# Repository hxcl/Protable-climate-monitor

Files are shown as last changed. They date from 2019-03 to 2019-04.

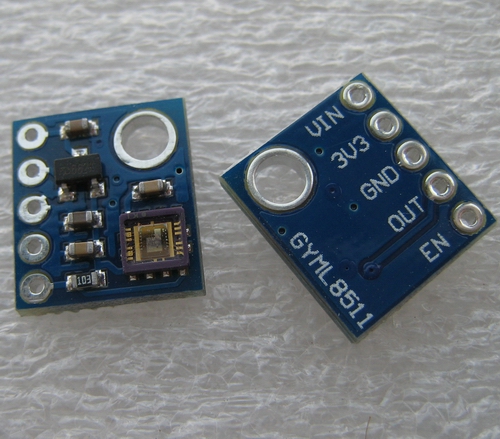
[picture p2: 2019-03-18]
sensor/ultraviolet sensor/GYML8511资料/ML8511-1.JPG

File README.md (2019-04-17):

# 便携式气候监测仪
最终代码和模型在Final文件夹内

---

确定的方案为：

* 智能窗户

  > 可根据室外环境智能打开/关闭百叶窗，用于宿舍
  >
  > 上位机可拆卸并随身携带，用于旅途

  分为两部分：

  * 上位机：便携模块

    需要的器件有：

    * 芯片为51单片机或Arduino
    * 温度传感器，湿度传感器，光传感器，（未确定：红外传感器，PM2.5传感器）
    * OLED屏幕
    * 微动按键/触摸按键

  * 下位机：驱动模块

    需要的器件有：

    * 百叶窗(59*90cm)
    * 步进电机
    * 驱动芯片（51单片机或Arduino）

用户操作：

* 安装：

  将百叶窗装好后，将电机转子安装到转轴处，将电机外壳与驱动模块固定住，驱动模块接上电源（mirco USB与手机充电器），将便携模块插到驱动模块上。

* 设定驱动模块：

  按驱动模块的`开窗`或`关窗`键将百叶窗调到中间状态，再按`复位`键，指示灯闪烁，则驱动模块完成预设。

* 设定便携模块：

  打开开关，屏幕会显示当前的温度、湿度、光照强度和紫外线强度，则此时工作正常；

  便携模块已根据广东的天气预设了智能关窗的阈值，也可以手动设置阈值。按`设置`按钮，此时屏幕上闪烁的为温度阈值，按`上`和`下`键调整；再`设置`键可切换到其他参数。只要有任意一项达到阈值，窗户就会关闭。未达到阈值时，窗户会线性调整开合角度。

* 便携模块的移动使用：

  将便携模块取下，可随身携带，适合旅游时了解当地的天气情况。只需要拿出来，将有传感器一面向上，按`显示`键，即可显示此时的天气，进而决定是否需要涂防晒霜/打遮阳伞。可以将它挂在包外实时监测，若超过阈值，指示灯显示为红色。

---

讨论后放弃的方案有这几种：

* 智能门锁

  > 用人脸识别开宿舍门

* 智能坐垫

  > 体重记录，久坐提醒
  >
  > 图书馆座位管理
* 智能书箱

  >智能准备第二天的书
* 智能运输车

  >自动跟随运输车

* 智能ppt

  >用语音控制ppt翻页

* 智能收作业

  > 用RFID管理身份，自动分类

* 智能

另外记录一个创意: 

* 共享校园网

  > 收集大二、大三、大四同学限制的校园网账号，储存在服务器中
  >
  > 大一同学付费后，可通过软件自动联网

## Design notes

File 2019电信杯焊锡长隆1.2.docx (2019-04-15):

FinO便携气候监测仪

——智能百叶窗

队伍名 焊锡长隆

队长 周镇峰

队员 刘宇帆

队员 杨联标

# 1、 功能说明和选题背景

FinO便携气候监测仪（以下简称FinO）可以监测紫外线强度，光照强度、温度和湿度，并通过屏幕显示出来。其体积小，待机长，可随身携带，随时随地得到当前位置的气候信息，弥补天气预报泛而不精的缺点，从而帮助您决定是否要增添衣服、涂抹防晒霜。

另外，FinO还可通过FinO特殊的USB口将数据输出。你只需将FinO插入FinO生态设备，即可享受智能家居。比如在这个项目中，我们打造了一个智能百叶窗，它能根据光照调智能整开合角度，让您的室内舒适明亮。未来，将有更多设备加入FinO生态。

# 二、整机电路

## 2.1 原理方框图

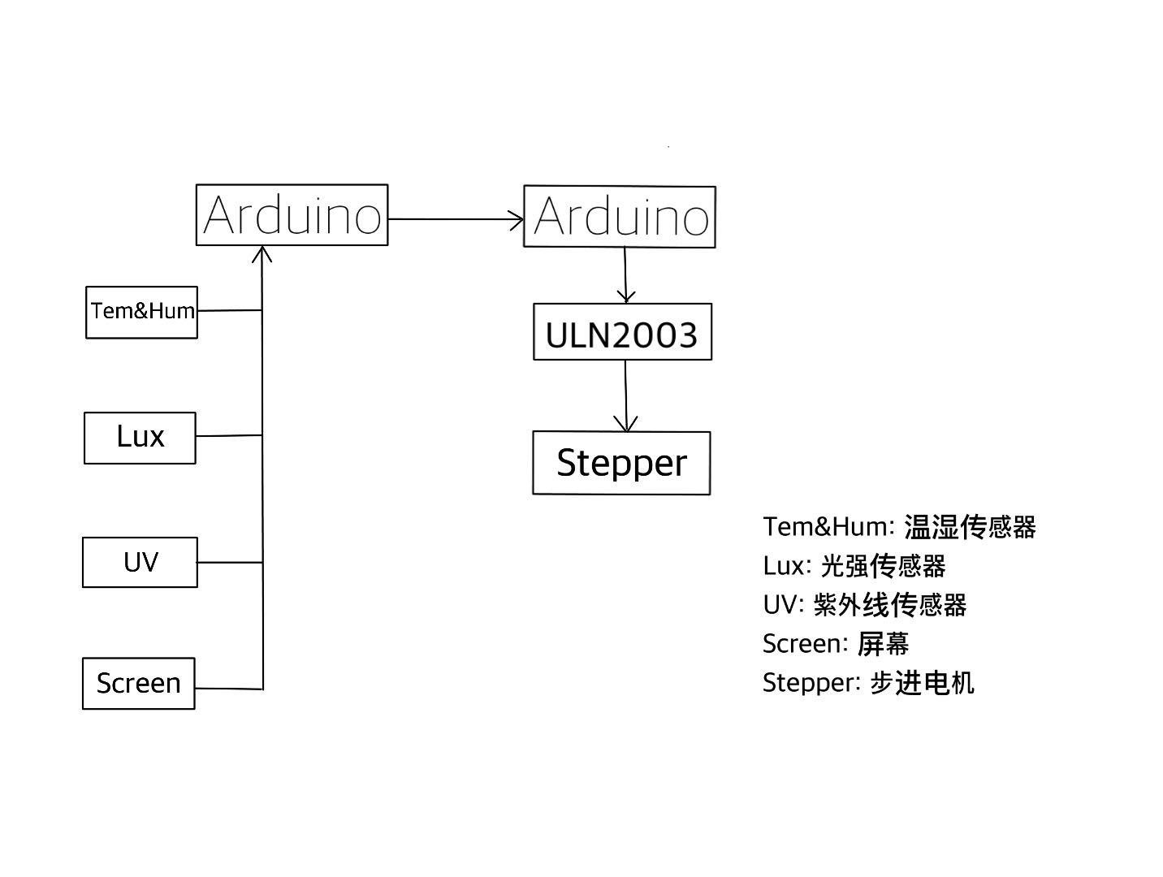
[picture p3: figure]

（图2.1）

## 2.2 整机电路图

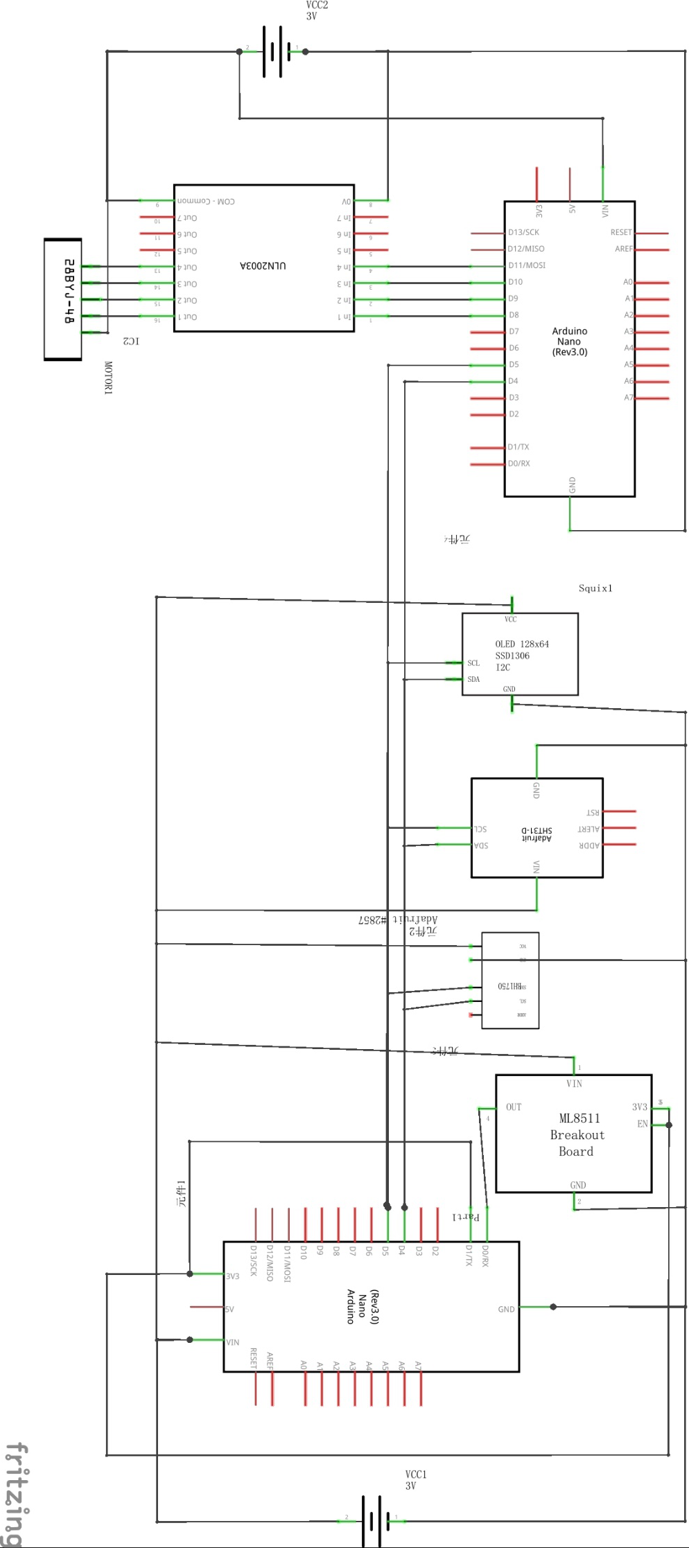
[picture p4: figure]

## （图2.2-1）

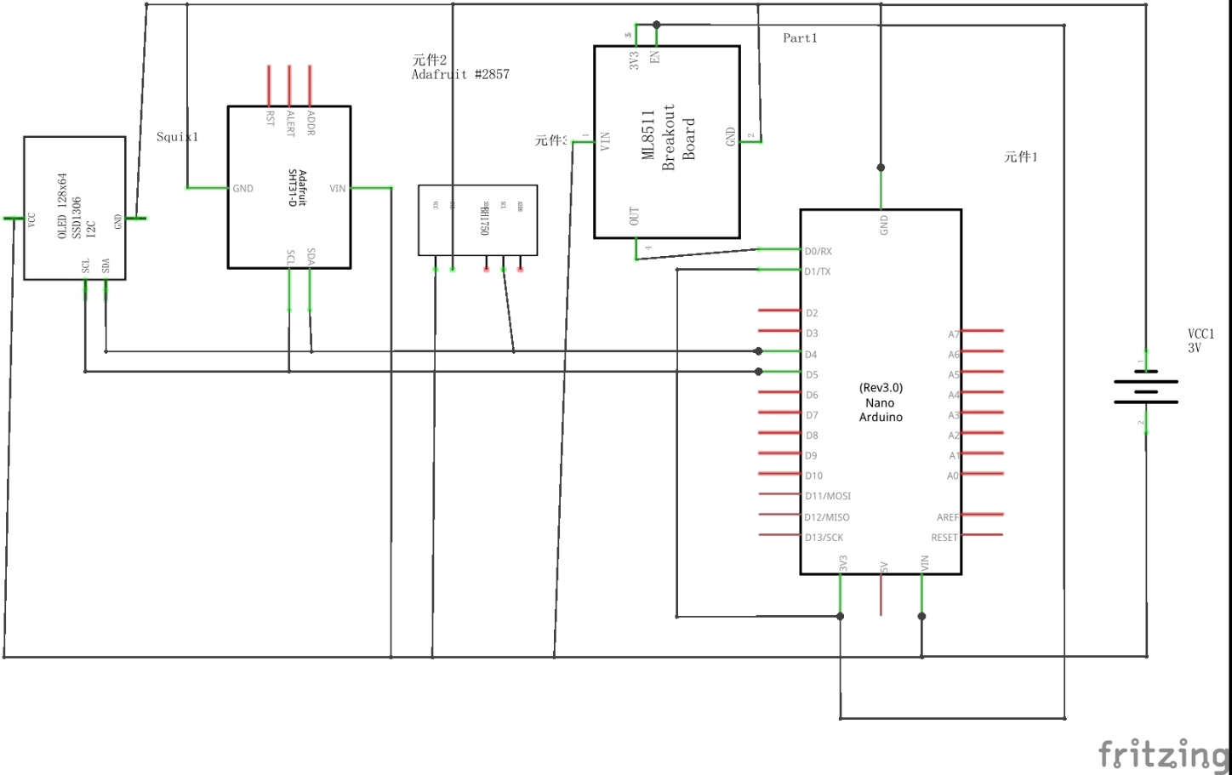
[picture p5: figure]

(图2.2-2)

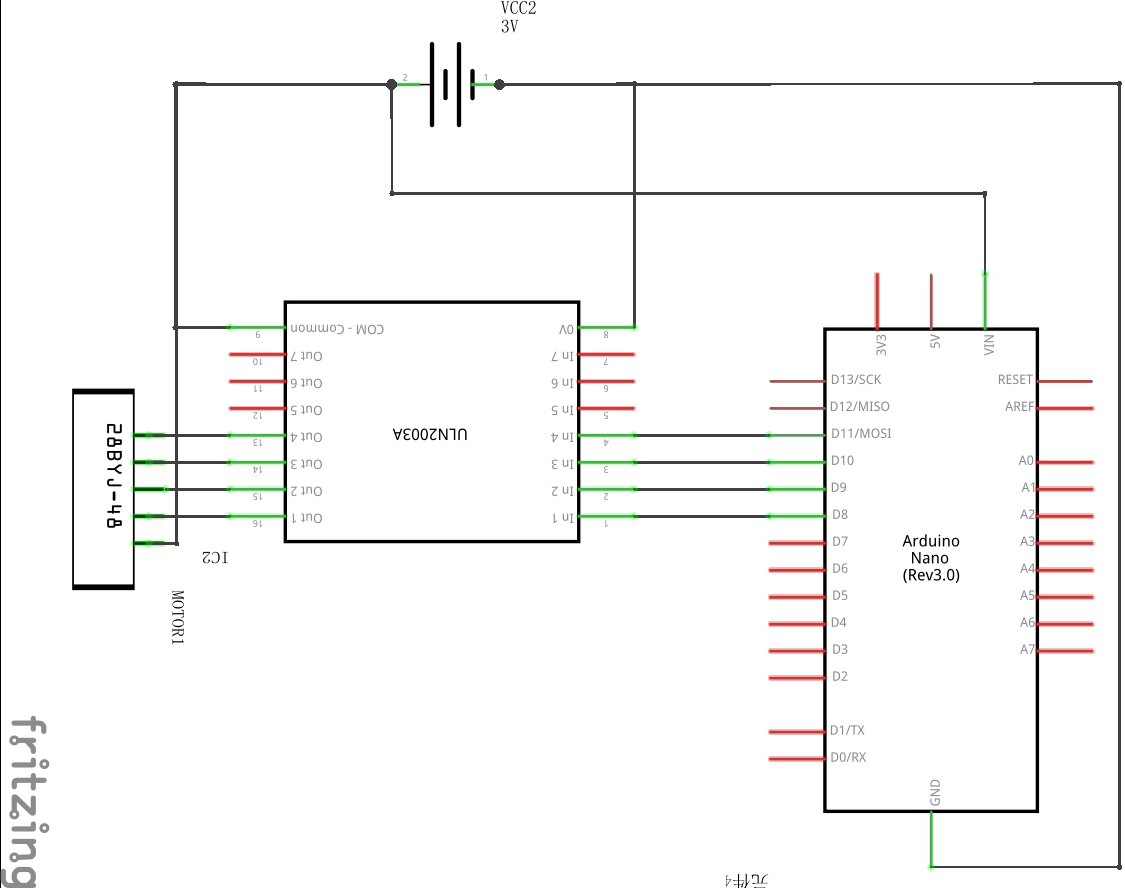
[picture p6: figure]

（图2.2-3）

# 三、单元电路设计

## 3.1 温湿度传感器模块——SHT3x-DIS

### 3.1.1 模块单元电路图

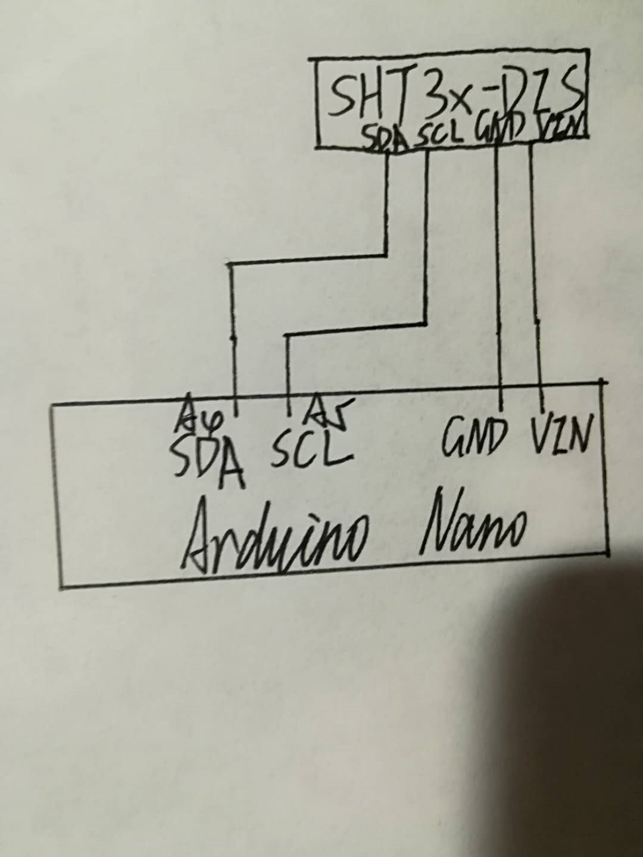
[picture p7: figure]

（图3.1.1）

### 3.1.2 核心元件简介

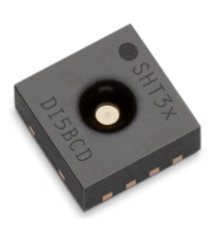
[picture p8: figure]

（图3.1.2）

SHT3x-DIS是校准刻度线性化的温湿度传感器。它的工作电压从2.4V到5.5V，使用I2C通信，拥有两个供用户选择的地址，精度范围为正负2%RH和正负0.3%摄氏度

### 3.1.3 模块功能及工作原理

温度测量的原理是：采用热电偶的方法，热电偶由两种不同材料的金属丝组成，两种丝材的一端焊接在一起，形成工作端，置于被测温度处；另一端称为自由端，与测量仪表相连，形成一个闭合回路。当工作端与自由端的温度不同时，回路中就会出现热电动势，经过电路的转换将这个电压的变化送到单片机，转化成机器能够识别的信号。

湿度测量的原理是：使用沉积在两个导电电极上的聚胺盐或醋酸纤维聚合物薄膜。当薄膜吸水或失水后，会改变两个电极间的介电常数，进而引起电容器容量的变化，利用外部测量电路可将电容器的容量变化进行捕捉、转化处理，最终在输出端显示成易识别的信号。

## 3.2 紫外线传感器模块

### 3.2.1 模块单元电路图（图3.2.1）

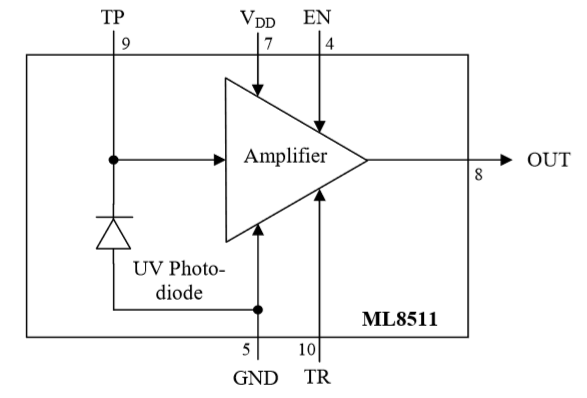
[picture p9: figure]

### 3.2.2 核心元件简介

ML8511紫外线传感器可读取室内或户外的紫外线强度，并转化为电压输出。

### 3.2.3 模块功能及工作原理

ML8511内部的光电二极管对UV-A和UV-B两种紫外线敏感（UV-C已被臭氧层吸收，无需测量），光电二极管产生的光电流通过运算放大器转换为电压。在-25℃到75℃的范围内，0~15级紫外线强度线性地输出为1~3伏电压。

## 3.3 光照强度传感器模块

### 3.3.1 模块单元电路图

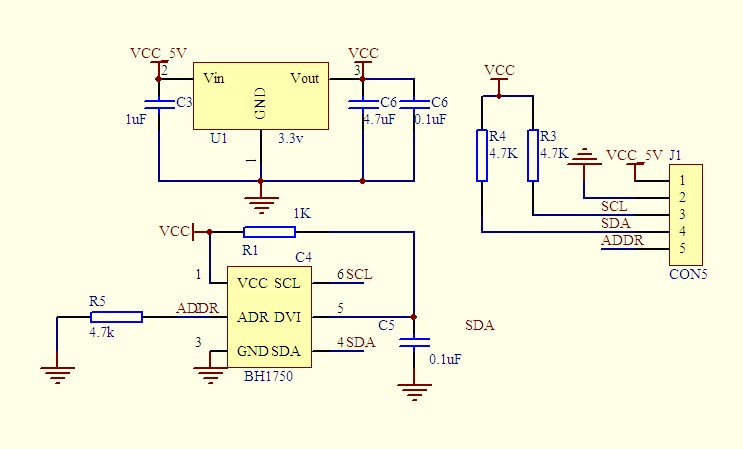
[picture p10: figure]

（图3.3.1）

### 3.3.2 核心元件简介

BH1750FVI是一种使用I2C协议的数字环境光传感集成电路。该集成电路最适合于获取手机LCD和键盘背光电源调节所需的环境光数据。拥有极高的感光范围（1-65536流明）。

### 3.2.3 模块功能及工作原理

### BH1750通过光敏二极管测量光强，光强信号经过集成运算放大器处理后输出

## 3.4 OLED显示屏模块

### 3.4.1 模块单元电路图

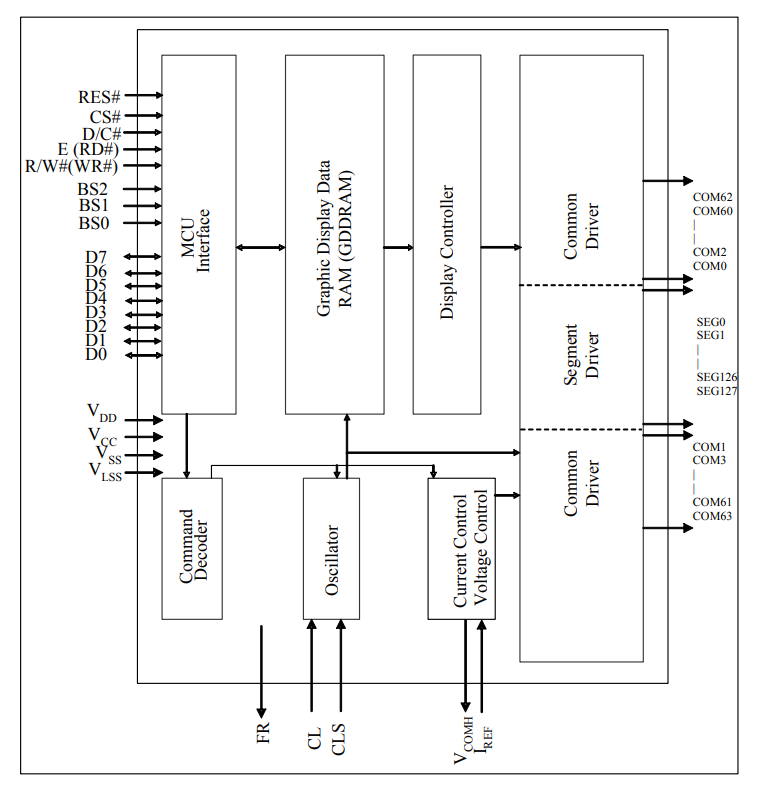
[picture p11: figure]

（图3.4.1）

### 3.4.2 核心元件简介

OLED显示屏模块分辨率为128x64，驱动芯片为SSD1306，采用I2C通信。

### 3.4.3 模块功能及工作原理

OLED（Organic Light-Emitting Diode）称为有机发光二极管，其原理为：在外界电压的驱动下，由电极注入的电子和空穴在发光层中复合形成处于束缚能级的电子空穴对即激子，激子辐射退激发发出光子，产生可见光。

利用U8g2lib库向SSD1306的缓冲区写入像素，再由SSD1306输出到OLED屏幕上

## 3.5 步进电机模块

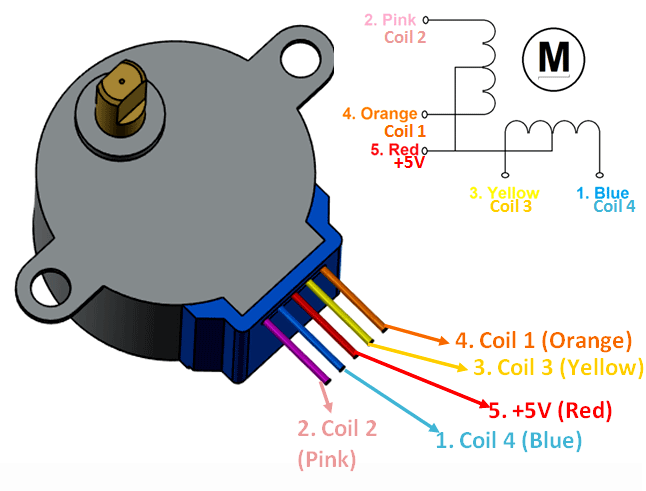
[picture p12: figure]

### 3.5.1 模块单元电路图

（图3.5.1-1）

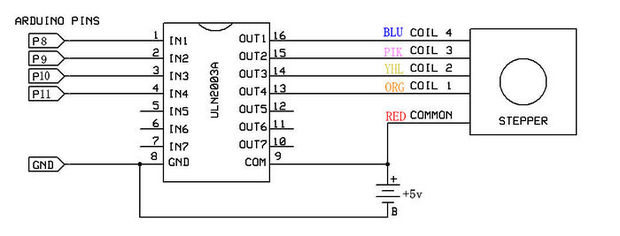
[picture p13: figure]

(图3.5.1-2)

### 3.5.2 核心元件简介

28BYJ48为常见的5V五线四相步进电机，利用ULN2003作为驱动芯片。

### 3.5.3 模块功能及工作原理

步进电机用于开关百叶窗，其原理为：按一定时序给定子通电，使其产生一个旋转的磁场，从而带动永磁式转子转动。

由于Arduino不能直接驱动功率较大的步进电机，采用ULN2003驱动。ULN2003的原理为：输入通过达林顿三极管控制反相输出。

# 四、程序代码

## 主机程序：

#include<Arduino.h>

#include <U8g2lib.h>

#include <Wire.h>

#include "SHTSensor.h"

SHTSensor sht;//温湿度传感器的对象

int BH1750address=0x23;//光强传感器地址

byte buff[2];

int UVOUT = A0; //Output from the sensor

int REF_3V3 = A1; //3.3V power on the Arduino board

unsigned int time=0;

float Lux,Tem,Hum,Uv,UVMAX=0;

U8G2_SSD1306_128X64_NONAME_F_HW_I2C u8g2(U8G2_R0, /* reset=*/ U8X8_PIN_NONE);

void setup() {

Serial.begin(9600);

u8g2.setI2CAddress(0x78);//屏幕地址

u8g2.begin();

Wire.begin();

}

void loop() {

firstDisplay();

u8g2.setFont(u8g2_font_victoriabold8_8r);

while(1){

u8g2.clearBuffer();

u8g2.drawFrame(4,4,120,56);

u8g2.drawHLine(4,32,120);

u8g2.drawVLine(64,4,56); //以上是屏幕初始化

float X,Y,Z;

int L=0;

tem_hum(X,Y); //读取温湿度X是温度，Y是湿度

uv(Z); //读取紫外线指数

L=light(); //读取光强

Trans(); //传输光强

if(UVMAX<Z) //以下是屏幕显示

{

UVMAX=Z;

}

u8g2.setCursor(6,13);

u8g2.print("Temp:");

u8g2.setCursor(6,26);

u8g2.print(X);

u8g2.setCursor(66,13);

u8g2.print("Hum:");

u8g2.setCursor(66,26);

u8g2.print(Y);

u8g2.setCursor(6,41);

u8g2.print("Lux:");

u8g2.setCursor(6,54);

u8g2.print(L);

u8g2.setCursor(66,41);

u8g2.print("UV:");

u8g2.setCursor(66,54);

u8g2.print(UVMAX);

u8g2.sendBuffer();

delay(2000);

}

}

//HXCL logo

void firstDisplay(){

u8g2.clear();

u8g2.setFont(u8g2_font_maniac_tr);

u8g2.drawBox(4,4,120,56);

u8g2.setDrawColor(0);

u8g2.setFontMode(1);

u8g2.drawStr(25,40,"HXCL");

u8g2.sendBuffer();

u8g2.setDrawColor(1);

delay(1500);

}

void Trans() //传输函数

{

Wire.beginTransmission(0x99);//括号内补充从机地址

Wire.write(buff [0]);

Wire.write(buff [1]);

Wire.endTransmission();

}

void tem_hum(float &x,float &y) //获取温湿度函数

{

if (sht.init());

sht.setAccuracy(SHTSensor::SHT_ACCURACY_MEDIUM);

if (sht.readSample())

{

y=sht.getHumidity();x=sht.getTemperature();

}

}

void uv(float &uvIntensity) //获取紫外线函数

{

int uvLevel = averageAnalogRead(UVOUT);

int refLevel = averageAnalogRead(REF_3V3);

//Use the 3.3V power pin as a reference to get a very accurate output value from sensor

float outputVoltage = 3.3 / refLevel * uvLevel;

//uvIntensity = mapfloat(outputVoltage, 0.99, 2.9, 0.0, 15.0);

uvIntensity = (outputVoltage - 0.99) * 15.0 / 1.91;

}

//Takes an average of readings on a given pin

//Returns the average

int averageAnalogRead(int pinToRead)

{

byte numberOfReadings = 16;

unsigned int runningValue = 0;

for(int x = 0 ; x < numberOfReadings ; x++)

runningValue += analogRead(pinToRead);

runningValue /= numberOfReadings;

return(runningValue);

}

int light(){ //获取光强函数

int i;

double lux=0;

BH1750_Init(BH1750address);

if(2==BH1750_Read(BH1750address)){

lux=((buff[0]<<8)|buff[1])/1.2; //数据处理

}

return lux;

}

int BH1750_Read(int address){

int i=0;

Wire.beginTransmission(address);

Wire.requestFrom(address, 2);

while(Wire.available()){

buff[i] = Wire.read(); // receive one byte

i++;

}

Wire.endTransmission();

return i;

}

void BH1750_Init(int address){

Wire.beginTransmission(address);

Wire.write(0x10);//1lx reolution 120ms

Wire.endTransmission();

}

## 从机程序：

#include<Arduino.h>

#include <Wire.h>

#define IN1 8

#define IN2 9

#define IN3 10

#define IN4 11

int x[14];

int clockwise=0,states;

int a=200,b=500;//光强的上下界，初始值为起居室的适宜光强

unsigned int mode=1;//光照模式，0，1，2三档，初始值为第一档；

void rotate(int,int);

unsigned long triggertime=0;

union temp

{

float Float;

byte Byte[4];

}temp1;

void setup()

{

pinMode(IN1,OUTPUT);

pinMode(IN2,OUTPUT);

pinMode(IN3,OUTPUT);

pinMode(IN4,OUTPUT);

Serial.begin(9600);

rotate(102,0); //百叶窗启动调零

delay(1000);

rotate(102,0);

delay(1000);

rotate(102,0);

delay(1000);

rotate(102,0);

delay(1000);

rotate(102,1);

Wire.begin(0x99); //括号内补充本机地址，作为从机

Wire.onReceive(receiveEvent); //接收数据的函数

attachInterrupt(0,changeMode,FALLING); //添加按键中断

states=1;

}

void changeMode() //按键中断修改模式函数

{

if(millis()-triggertime>100) //消除抖动

{

triggertime=millis();

mode++;

mode=mode%3;

switch (mode)

{

case 0:a=0;b=200;break;

case 1:a=200;b=500;break;

case 2:a=500;b=800;break;

}

}

}

void receiveEvent()

{

int L;

while(Wire.available()>0)

{

for(int i=0;i<14;i++)

{

x[i]=Wire.read();

}

L=((x[0]<<8) | x[1])/1.2;

}

for(int i=2;i<6;i++)

{

temp1.Byte[i-2]=x[i];

}

Serial.println(temp1.Float);

for(int i=6;i<10;i++)

{

temp1.Byte[i-6]=x[i];

}

Serial.println(temp1.Float);

for(int i=10;i<14;i++)

{

temp1.Byte[i-10]=x[i];

}

Serial.println(temp1.Float);

Serial.println(L);

clockwise=judge(a,b,L);

if(clockwise==1&&states!=0) //states记录电机的当前位置

{

rotate(50,clockwise);

states--;

}

if(clockwise==0&&states!=10) //states记录电机的当前位置

{

rotate(50,clockwise);

states++;

}

}

int judge(int a,int b,float L) //判断当前光强是否是

{ //预定范围

if(L>=a&&L<=b) return -1;

else if(L<a) return 0;

else return 1;

}

void STEP(int i) //驱动步进电机的函数

{

switch (i)

{

case 0:

{

digitalWrite(IN1, 0);

digitalWrite(IN2, 1);

digitalWrite(IN3, 1);

digitalWrite(IN4, 1);

break;

}

case 1:

{

digitalWrite(IN1, 0);

digitalWrite(IN2, 0);

digitalWrite(IN3, 1);

digitalWrite(IN4, 1);

break;

}

case 2:

{

digitalWrite(IN1, 1);

digitalWrite(IN2, 0);

digitalWrite(IN3, 1);

digitalWrite(IN4, 1);

break;

}

case 3:

{

digitalWrite(IN1, 1);

digitalWrite(IN2, 0);

digitalWrite(IN3, 0);

digitalWrite(IN4, 1);

break;

}

case 4:

{

digitalWrite(IN1, 1);

digitalWrite(IN2, 1);

digitalWrite(IN3, 0);

digitalWrite(IN4, 1);

break;

}

case 5:

{

digitalWrite(IN1, 1);

digitalWrite(IN2, 1);

digitalWrite(IN3, 0);

digitalWrite(IN4, 0);

}

case 6:

{

digitalWrite(IN1, 1);

digitalWrite(IN2, 1);

digitalWrite(IN3, 1);

digitalWrite(IN4, 0);

break;

}

case 7:

{

digitalWrite(IN1, 0);

digitalWrite(IN2, 1);

digitalWrite(IN3, 1);

digitalWrite(IN4, 0);

break;

}

case 8:

{

digitalWrite(IN1, 0);

digitalWrite(IN2, 0);

digitalWrite(IN3, 0);

digitalWrite(IN4, 0);

break;

}

}

}

void rotate(int times, int clockwise=1)

{

//times为多少次8相，times=512对应一周。

//clockwise是标记顺逆时针，0为顺时针转动，1为逆时针转动

int j=times;

while(j--)

{

if(clockwise==0)

{

for(int i=0;i<8;++i)

{

STEP(i);

delay(2);

}

STEP(8);

delay(1);

}

if(clockwise==1)

{

for(int i=7;i>=0;--i)

{

STEP(i);

delay(2);

}

STEP(8);

delay(1);

}

}

}

void loop()

{

STEP(8);

delay(1000);

}

6 执着理想 勇于开拓

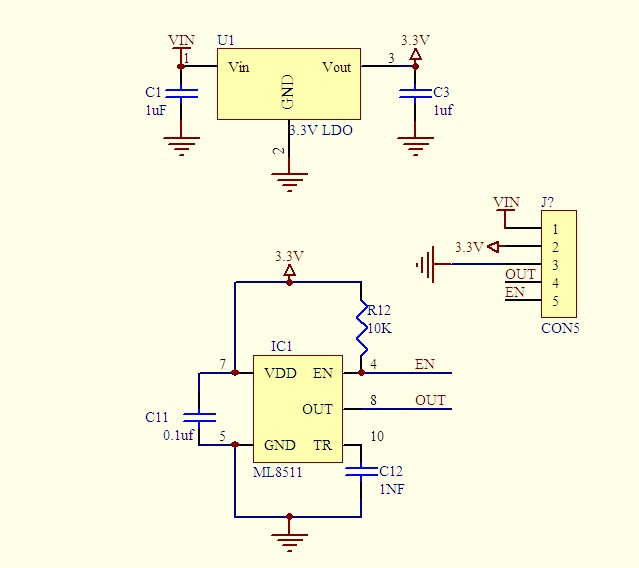
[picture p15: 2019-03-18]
sensor/ultraviolet sensor/GYML8511资料/GYML8511_SCH.jpg

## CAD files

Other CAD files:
sensor/muti-function sensor/GY-39/通信程序/C51/c51_usart/output/main.obj
sensor/temperature&humidity sensor/XL7021-售后资料/STC89C52-SI7021/TEST-SI7021/OUT/USER-MAIN.obj
sensor/muti-function sensor/GY-39/通信程序/C51/c51_iic/output/main.obj
sensor/light sensor/GY-302/测试程序/STC51/STC_BH1750/STC_BH1750.OBJ
sensor/light sensor/GY-30光强度资料V1/GY-30资料/测试程序/STC_GY-30/STC_BH1750/STARTUP.OBJ
sensor/light sensor/GY-30光强度资料V1/测试程序/STC_GY-30/STC_BH1750/STC_BH1750.OBJ
sensor/muti-function sensor/GY-39/通信程序/C51/c51_iic/output/usart.obj
sensor/muti-function sensor/GY-39/通信程序/C51/c51_usart/output/usart.obj
sensor/temperature&humidity sensor/XL7021-售后资料/STC89C52-SI7021/TEST-SI7021/OUT/MCU-STC11L04.obj
sensor/light sensor/GY-302/测试程序/STC51/STC_BH1750/STARTUP.OBJ
sensor/light sensor/GY-30光强度资料V1/GY-30资料/测试程序/STC_GY-30/STC_BH1750/STC_BH1750.OBJ
sensor/light sensor/GY-30光强度资料V1/测试程序/STC_GY-30/STC_BH1750/STARTUP.OBJ
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

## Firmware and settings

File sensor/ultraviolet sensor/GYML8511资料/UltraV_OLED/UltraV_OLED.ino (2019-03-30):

   /* 
 Fabio Marzocca @ 2018
 Analog to digital conversions rely completely on VCC. We assume
 this is 5V but if the board is powered from USB this may be as high as 5.25V or as low as 4.75V:
 http://en.wikipedia.org/wiki/USB#Power Because of this unknown window it makes the ADC fairly inaccurate
 in most cases. To fix this, we use the very accurate onboard 3.3V reference (accurate within 1%). So by doing an
 ADC on the 3.3V pin (A1) and then comparing this against the reading from the sensor we can extrapolate
 a true-to-life reading no matter what VIN is (as long as it's above 3.4V).

v. 2.0.0 - July 2018
   - moved from 16x2 LCD to OLED
v. 2.0.1 - Sept 2018
   - changed read battery function
*/

#include <Arduino.h>
#include <U8g2lib.h>
#include <Wire.h>

U8G2_SSD1306_128X64_NONAME_F_HW_I2C u8g2(U8G2_R0, /* clock=*/ SCL, /* data=*/ SDA, /* reset=*/ U8X8_PIN_NONE);   // All Boards without Reset of the Display

#define FIRST_ROW_Y 16
#define FIRST_ROW_X 16
#define BOX_H 38

//Hardware pin definitions
const int UVOUT = A0; //Output from the sensor
const int REF_3V3 = A1; //3.3V power on the Arduino board
const int VBATT = A2; //Battery voltage

float maxUV = 0; //Max UV index read


void setup()
{ 
  pinMode(UVOUT, INPUT);
  pinMode(REF_3V3, INPUT);
  pinMode(VBATT, INPUT);
 
  u8g2.begin();

}

void loop()
{
  u8g2.firstPage();
  do {
    int uvLevel = averageAnalogRead(UVOUT);
    int refLevel = averageAnalogRead(REF_3V3);

    //Use the 3.3V power pin as a reference to get a very accurate output value from sensor
    float outputVoltage = 3.3 / refLevel * uvLevel;

    float uvIntensity = mapfloat(outputVoltage, 0.99, 2.6, 0.0, 15.0); //Convert the voltage to a UV intensity level

    readBattery();
    if (maxUV < uvIntensity) {
        maxUV = uvIntensity;
      }
    u8g2.drawFrame(0,FIRST_ROW_Y+1,128,BOX_H);
    u8g2.setFont(u8g2_font_logisoso18_tf);

    //Instant UV
    u8g2.setCursor(10,40);
    u8g2.print(uvIntensity);
    //UV Max
    u8g2.setCursor(70,40);
    u8g2.print(maxUV);

    u8g2.setFont(u8g2_font_u8glib_4_tf);
    u8g2.setCursor(10,52); u8g2.print(F("INSTANT"));
    u8g2.setCursor(75,52); u8g2.print(F("MAXIMUM"));

    showUVCategory();
    u8g2.setCursor(88,64); u8g2.print(F("F.Marzocca"));
    
   } while ( u8g2.nextPage() );
  delay(200);
}

// Reads maxUV and prints the UV category
void showUVCategory() {
  char strCat[12];

  byte categ = (byte)(maxUV+0.5);  //round up
  if ((categ >= 0) && (categ < 3)) {
    strcpy(strCat, "LOW"); 
  } else if ((categ >= 3) && (categ < 6)) {
    strcpy(strCat, "MODERATE");
  } else if ((categ >= 6) && (categ < 8)) {
    strcpy(strCat, "HIGH !");
  } else if ((categ >= 8) && (categ < 10)) {
     strcpy(strCat, "VERY HIGH!");
  } else if (categ >= 11) {
    strcpy(strCat, "EXTREME!");
  }
  
   u8g2.setCursor(0,64);
   u8g2.print(strCat);
  
}

//Takes an average of readings on a given pin
//Returns the average
int averageAnalogRead(int pinToRead)
{
  byte numberOfReadings = 16;
  unsigned int runningValue = 0; 

  for(int x = 0 ; x < numberOfReadings ; x++)
    runningValue += analogRead(pinToRead);
  runningValue /= numberOfReadings;

  return(runningValue);  
}

//The Arduino Map function but for floats
//From: http://forum.arduino.cc/index.php?topic=3922.0
float mapfloat(float x, float in_min, float in_max, float out_min, float out_max)
{
  return (x - in_min) * (out_max - out_min) / (in_max - in_min) + out_min;
}

void readBattery() {
   long battery = readBattVcc(); 
   long VccMin = 2300; //Battery minimum voltage read on Vcc
   byte batteryBar; //Battery progress bar
   int barStep = 140; //step for battery progress bar (235)

   batteryBar = (battery - VccMin)/barStep;
   
       //battery icon
    u8g2.setFont(u8g2_font_open_iconic_embedded_2x_t);
    u8g2.drawGlyph(1, FIRST_ROW_Y, 73 );
    
    // battery status cursor
    u8g2.setFont(u8g2_font_open_iconic_play_1x_t);
    for (byte i=1; i<=batteryBar; i++) {
       u8g2.drawGlyph( 128-9*i,FIRST_ROW_Y-4,75);
    }
    
    // battery voltage
    u8g2.setFont(u8g2_font_freedoomr10_tu);
    u8g2.setCursor(25, FIRST_ROW_Y);
    u8g2.print(float(battery)/1000, 3);
 
}


long readBattVcc()
{
    int sum=0;
    int sample_count=0;
    long voltage= 0;
    #define NUM_SAMPLES 10
    // take a number of analog samples and add them up
    while (sample_count < NUM_SAMPLES) {
        sum += analogRead(VBATT);
        sample_count++;
        delay(2);
    }
        // calculate the voltage
    // use 5000 for a 5.0V ADC reference voltage
    // 5020V is the calibrated reference voltage (in millivolts) for my project
    voltage = ((long)sum / (long)NUM_SAMPLES * 5020) / 1024.0;
    return voltage; //Vbattery in millivolts
}
    
    

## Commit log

2019-04-05 主从机通信程序
2019-04-15 Electronic Picture
    [Untitled Sketch 4.fzz]
